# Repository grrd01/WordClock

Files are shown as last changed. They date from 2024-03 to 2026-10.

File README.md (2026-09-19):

# grrd's WordClock

This repository contains the code for the LOLIN (WEMOS) D1 mini Lite (ESP8266) Wordclock offered by FabLab Bern:
[WordClock-Worshop @ FabLab Bern](https://fablab-bern.ch/wordclock-workshop/)

Generate custom clockface:
[SVG-Generator](https://wordclock.collaud.me/)

## Update Arduino Code with Current Frontend

The web interface is automatically generated from the Frontend using Grunt and embedded in `web_interface.h`:

```bash
cd Frontend
yarn install         # (only required on first run)
yarn grunt           # Compiles Frontend and updates web_interface.h
```

After running `yarn grunt`, the file `Backend/Arduino_Berndeutsch_121/web_interface.h` is automatically updated and ready to compile with the Arduino IDE.

The current sketch also supports the optional ESP32-C6 BLE controller. When compiling it for an ESP32, select the custom `partitions.csv` file in the partition scheme menu (or select `Huge APP` on boards that provide that option). The default ESP32 partition leaves only 1.3 MB for the application, which is too small for the web interface and BLE support together. The custom table reserves 3 MB for the application and requires a board with at least 4 MB flash.

Hardware required:

| Anz | Element | Bemerkungen | Preis |
|---:|---|---|---:|
| 1 | [IKEA SANNAHED Bilderrahmen](https://www.ikea.com/ch/en/p/sannahed-frame-black-60459118/) | 25x25cm schwarz | 10.00 |
| 1 | [Glasscheibe 25x25cm](https://www.jumbo.ch/de/bauen-renovieren/glas-kunstglas/kunstglas/floatglas-klar-3-mm/p/5840626) | | 10.00 |
| 1 | [Hartfaserplatte 25x25cm](https://www.jumbo.ch/de/bauen-renovieren/holz/holzzuschnitt/hartfaserplatten/hartfaserplatte-roh-3-mm/p/3890986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) | |  1.00 |
| 1 | [Diffusor](https://de.aliexpress.com/item/1005006113208369.html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) | LGT075J |  1.00 | 
| 1 | [Raster](https://github.com/grrd01/WordClock/blob/main/Hardware/3D_Grid/WordClock_25x25slim/WordClock%2025x25%20slim.stl) | 3D-Druck |  3.00 |
| 1 | [Wemos D1 mini V4.0 USB C](https://de.aliexpress.com/item/1005012133189139.html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) | |  2.00 |
| 0.5 | [LED RGB NeoPixel Stripe](https://de.aliexpress.com/item/2036819167.html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) | 5m, 60LED/m, IP30, not waterproove, white PCB |  9.00 | 
| 1 | [Kondensator 10V 1000µF](https://de.aliexpress.com/item/1005002524973878.html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) | |  0.30 |
| 1 | [Widerstand 470 Ohm](https://de.aliexpress.com/item/1005003342360099.html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) | |  0.05 |
| 1 | [USB-Kabel](https://www.temu.com/ch/60w-schnelllade-usb-typ-c-kabel-3-6-10ft--usb-a-zu-usb-c-ladekabel-kompatibel-mit-samsung-galaxy-iphone--plus-15-pro-15-pro-max-mehr-usb-c-ka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) | 2m |  2.00 |
| 0.5 | [Lötzinn](https://www.berrybase.ch/goobay-loetzinn-bleifrei-oe1-0mm/gewicht-17g-dispenser) | |  2.00 | 
| 2.25m | [Kupferlitze](https://www.berrybase.ch/kupferlitze-isoliert-1x0-14mm-10m/farbe-rot) | 3x75cm rot/blau/schwarz pro Uhr |  1.00 | 
|  10cm | [Schrumpfschlauch](https://de.aliexpress.com/item/4000967042670.html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) | 2mm | |
| 1 | [Controller-Mount](https://github.com/grrd01/WordClock/blob/main/Hardware/3D_Parts/Wemos%20D1%20mini%20Mount.stl) | | |
| 1 | [Cable-Mount](https://github.com/grrd01/WordClock/blob/main/Hardware/3D_Parts/USB-Cable%20Mount.stl) | | |
| 0.5 | [Farbspray](https://www.galaxus.ch/de/s4/product/amsterdam-spruehfarbe-lampenschwarz-040-l-lack-6300169) | | |
| x | [Lötkolben](https://de.aliexpress.com/item/1005005623832147.html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) | | |
| x | [Schmirgelpapier](https://de.aliexpress.com/item/1005005886525600.html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) | |  1.00 |
| x | [Schleifklotz](https://www.galaxus.ch/de/s4/product/walkron-schleifklotz-aus-kork-schleifmittel-37001841) | | |
| x | [Weissleim](https://www.galaxus.ch/de/s4/product/cementit-weiss-100g-mit-drehverschluss-100-g-klebstoff-5633901) | | |
| x | [Heissleim](https://www.galaxus.ch/de/s4/product/i-am-creative-klebesticks-heisskleber-11152396) | | |
| x | [Klebband](https://www.galaxus.ch/de/s4/product/tesa-4344-precision-standard-malerkrepp-fuer-praezises-abdecken-25-mm-klebeband-13502538) | | |

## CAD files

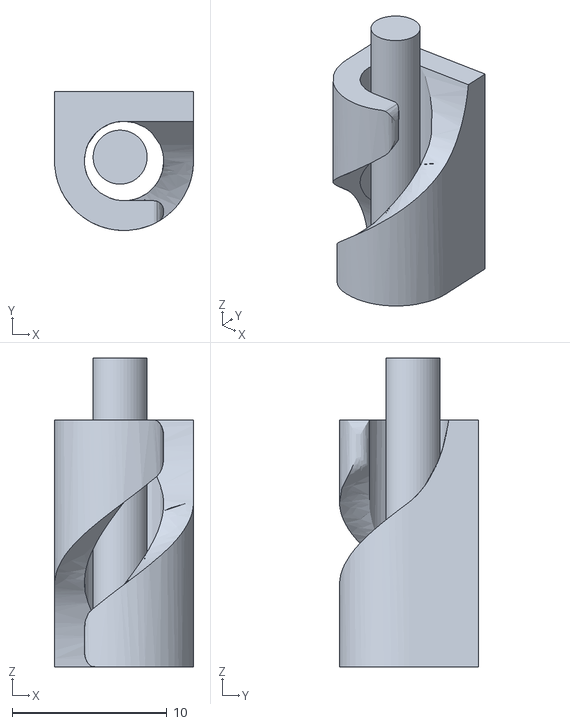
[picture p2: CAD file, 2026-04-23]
Hardware/3D_Parts/USB-Cable Mount.stl
9.00 x 9.00 x 20.0

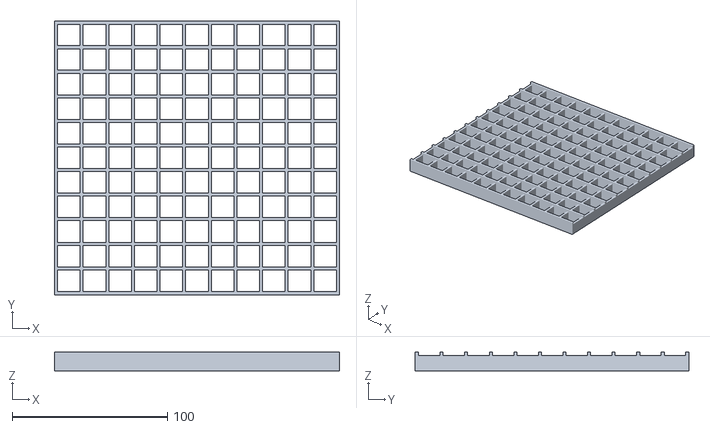
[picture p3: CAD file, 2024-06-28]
Hardware/3D_Parts/WordClock_25x25/WordClock_25x25.stl
183.5 x 176.2 x 12.0

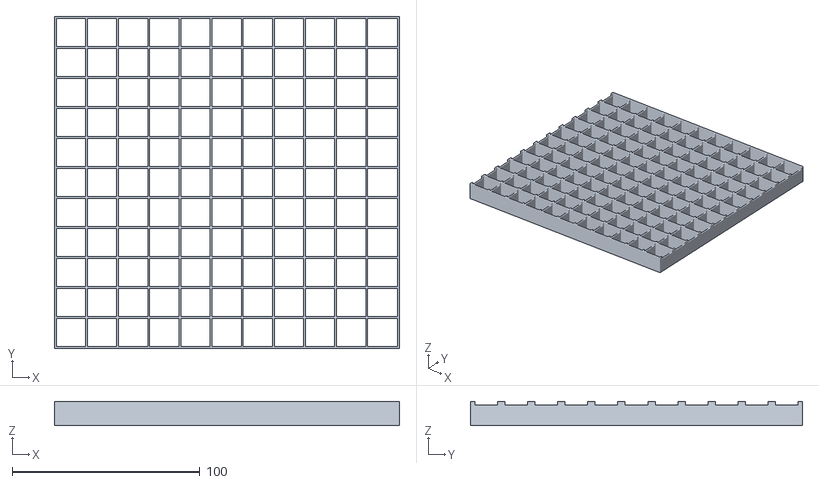
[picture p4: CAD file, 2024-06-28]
Hardware/3D_Parts/WordClock_25x25slim/WordClock 25x25 slim.stl
184.0 x 177.0 x 13.0

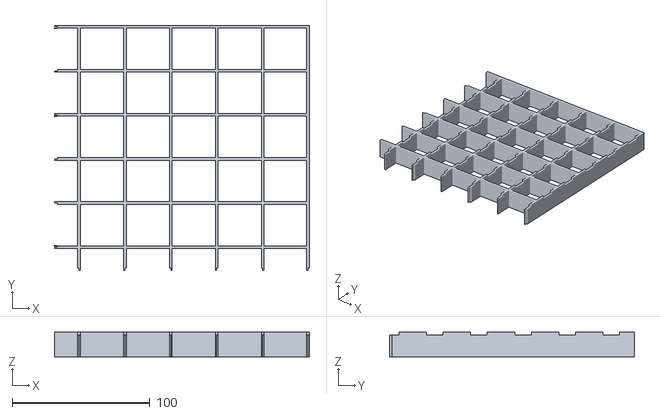
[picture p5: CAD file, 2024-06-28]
Hardware/3D_Parts/WordClock_50x50/WordClock_50x50_B.stl
185.0 x 178.1 x 18.0

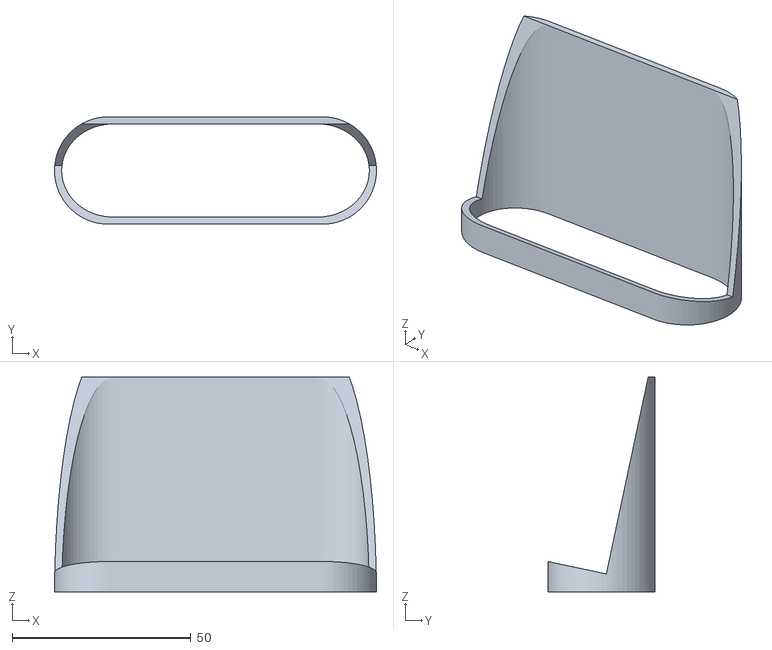
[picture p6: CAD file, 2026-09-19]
Hardware/3D_Parts/WordClock_9x9/WordClockMini_Ständer.stl
90.0 x 30.0 x 60.0

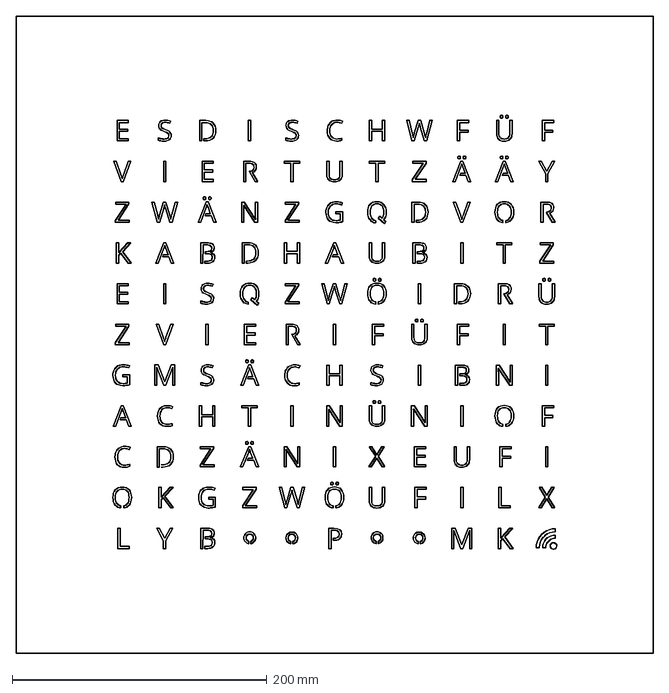
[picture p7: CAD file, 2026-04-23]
Hardware/Clockface/Berndeutsch/Berndeutsch_121_50x50_Stencil.dxf
500.0 x 500.0 mm

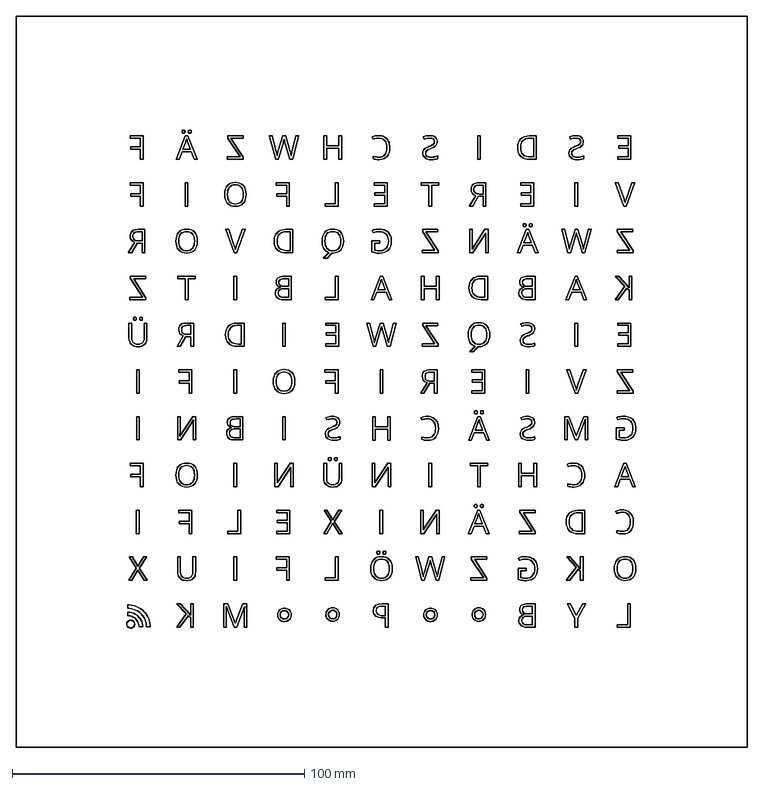
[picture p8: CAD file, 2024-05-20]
Hardware/Clockface/Zürideutsch/Zuerideutsch_121_25x25_Laser.dxf
250.0 x 250.0 mm

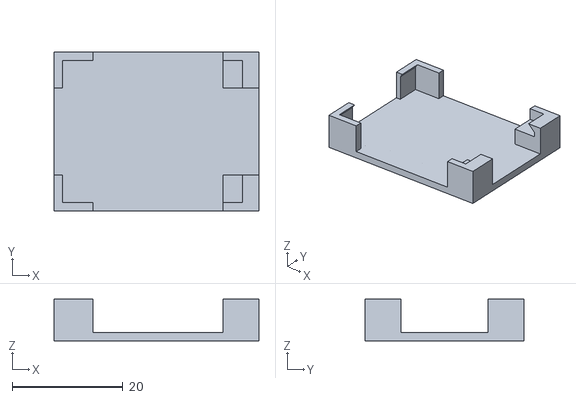
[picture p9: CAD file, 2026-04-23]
Hardware/3D_Parts/Wemos D1 mini Mount.stl
37.0 x 28.7 x 7.50

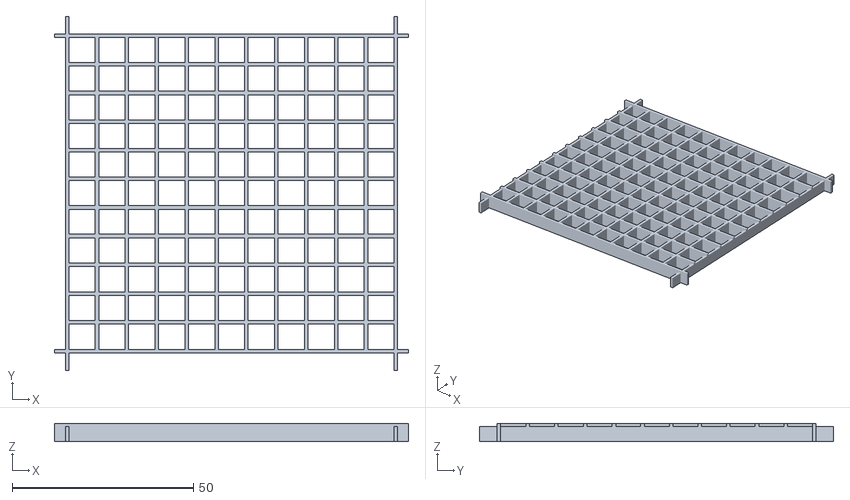
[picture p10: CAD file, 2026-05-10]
Hardware/3D_Parts/WordClock_9x9/WordClock_9x9.stl
97.8 x 97.8 x 5.00

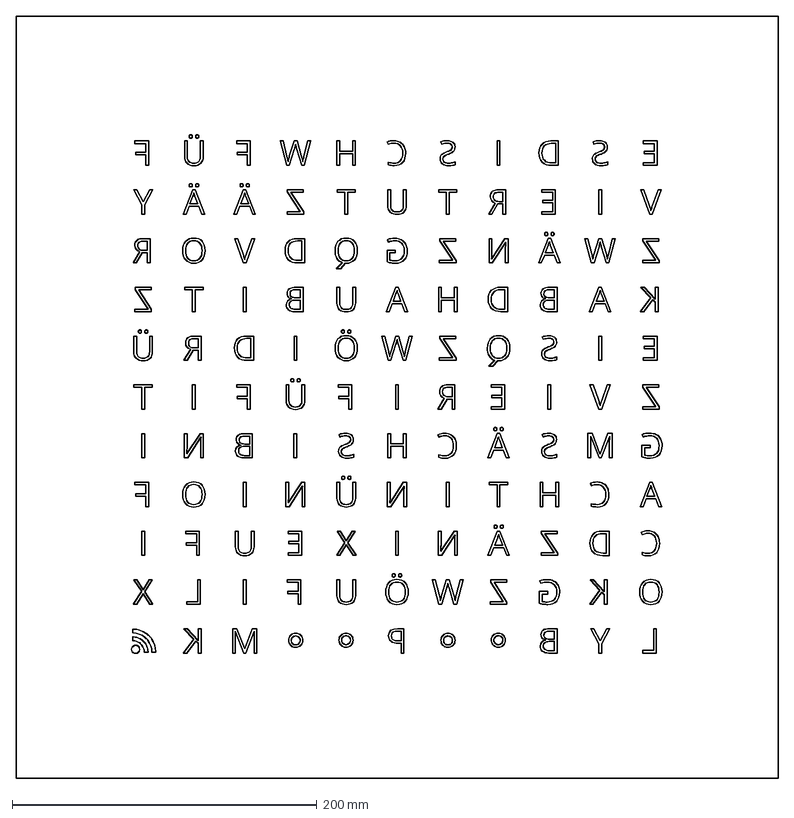
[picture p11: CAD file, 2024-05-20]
Hardware/Clockface/Berndeutsch/Berndeutsch_121_50x50_Laser.dxf
500.0 x 500.0 mm

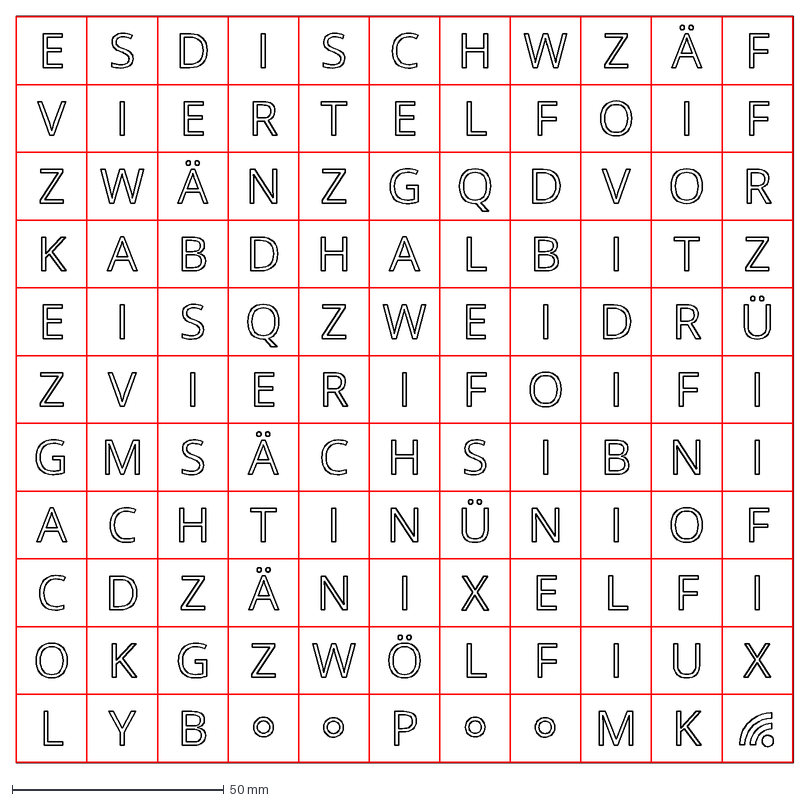
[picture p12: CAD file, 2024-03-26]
Hardware/Clockface/Zürideutsch/Zuerideutsch_121.dxf
183.5 x 176.2 mm

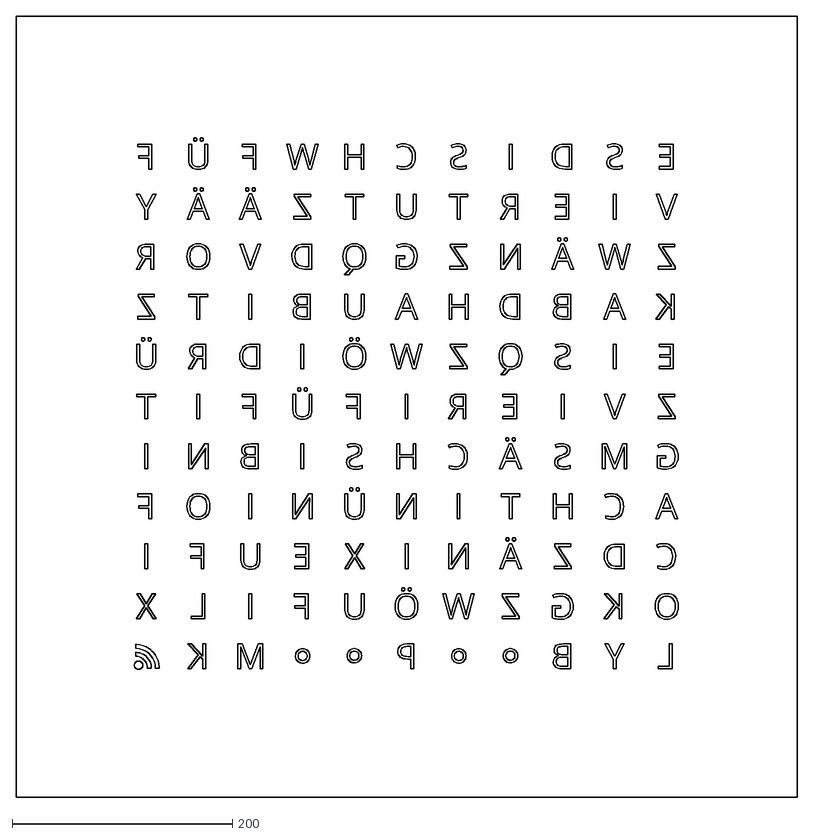
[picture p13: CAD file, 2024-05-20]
Hardware/Clockface/Berndeutsch/Berndeutsch_121_25x25_Laser.dxf
708.7 x 708.7

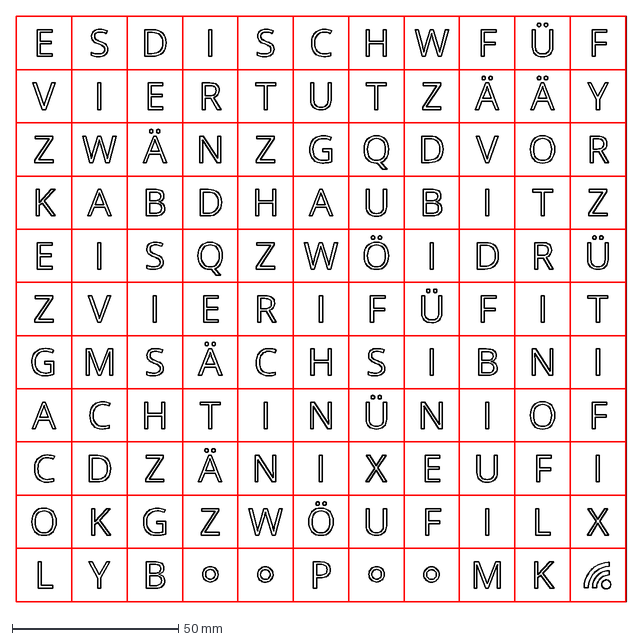
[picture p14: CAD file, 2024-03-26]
Hardware/Clockface/Berndeutsch/Berndeutsch_121.dxf
183.5 x 176.2 mm

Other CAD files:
Hardware/3D_Parts/WordClock_50x50/WordClock_50x50_A.stl

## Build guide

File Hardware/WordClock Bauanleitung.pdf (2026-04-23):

1.

2.
3.

4.

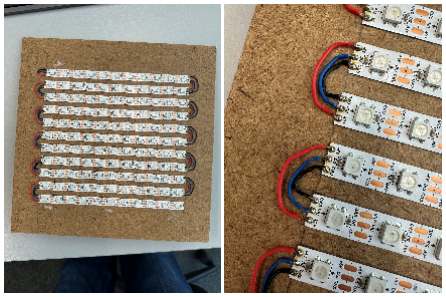
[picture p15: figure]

1.

2.
3.

4.

5.

# 2026 WordClock Bauanleitung

# 1. Clockface / Zifferblatt

Material: 25 x 25 cm Floatglas, Acrylspray

Mit Schleifpapier und Schleifklotz die scharfen Kanten abschleifen ACHTUNG: Die Glasscheibe hat scharfe Kanten und kann zerbrechen! Reinigen /Fingerabdrücke entfernen
Draussen auf Kartonunterlage mit Acrylspray einsprühen
ACHTUNG: Die Farbschicht ist sehr kratzempfindlich!
20 - 30 cm Abstand
mehrere dünne Schichten, Tropfenbildung vermeiden immer auf der selben Seite
horizontal / vertikal abwechseln
neben der Glasscheibe mit dem Sprühen beginnen 5 - 6 x wiederholen, bis kein Licht mehr durchscheint

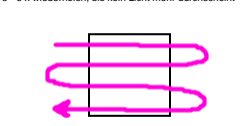
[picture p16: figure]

Wenn die Farbe trocken ist, Beschriftung auf dem Lasercutter einbrennen

# 2. LED-Panel

Material: 25 x 25 cm Hartfaserplatte, LED-Streifen, Kabel

Kabel zuschneiden, an beiden Enden 2 mm abisolieren: Rot (+5V): 1 * 300 mm, 5 * 30 mm, 5 * 49 mm
Blau (Din / Do): 1 * 300 mm, 10 * 38 mm
Schwarz (GND): 1 * 300 mm, 5 * 30 mm, 5 * 49 mm
Vom LED-Streifen 11 Stücke à 11 LEDs mit der Schere entlang der Trennlinie mittig durch die Kupferkontakte abschneiden LED-Streifen gemäss Aufzeichnung auf die Hartfaserplatte kleben
Blauen Schutzstreifen ablösen
ACHTUNG: Pfeilrichtung auf LED-Streifen muss der Aufzeichnung entsprechen!
Die abgeschnittenen Enden der LED-Streifen mit den vorbereiteten Kabelstücken wieder verbinden:
Mit Lötkolben die Kontaktstellen auf den LED-Streifen 2 Sekunden aufheizen, danach einen Tropfen Lötzinn über die Verbindungsstelle Die abisolierten Kabelstückchen so verdrehen, dass keine Kupferdrähtchen abstehen
Die Kabelstückchen mit Klebband auf einer Unterlage fixieren und sehr kurz mit dem Lötkolben aufheizen und mit ein wenig Lötzinn "verzinnen"
Mit Klebeband das passende Stück Kabel über dem Zinntropfen fixieren, den Tropfen mit dem Lötkolben aufheizen, bis das Kabel darin versinkt
Die langen Kabel (300mm) an die drei Kontakte (DIN = Data in, VBUS = +5V, GND = Ground) oben links anlöten und durchs Loch auf die Rückseite ziehen

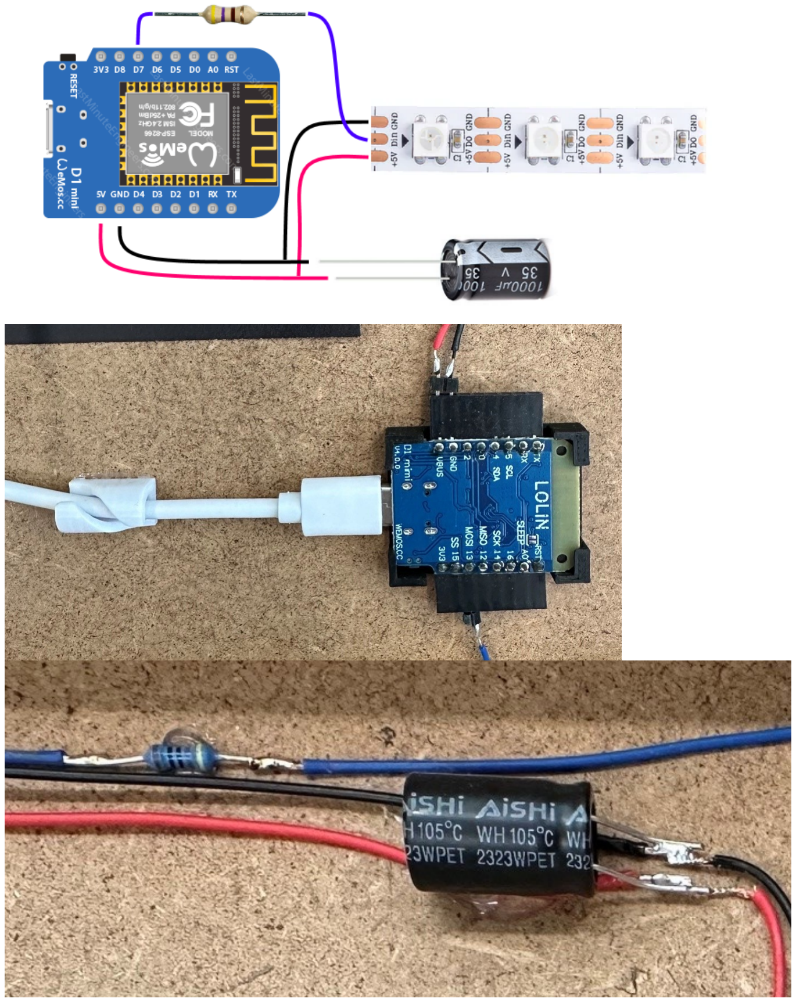
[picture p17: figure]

1.
2.

3.
4.
5.

# 3. Controller

Material: Wemos D1 mini, 1000mF Kondensator, 470 Ohm Widerstand, Steckverbindungen

Blaues Datenkabel trennen, 470 Ohm Widerstand dazwischen löten, mit Schrumpfschlauch isolieren Rotes und schwarzes Kabel parallel trennen, Kondensator anlöten
ACHTUNG: +/- Polung beachten!
mit Schrumpfschlauch isolieren
Weibliche Steckverbindung auf Controller löten
männliche Steckverbindung auf weibliche stecken Kabel am männlichen Header anlöten:
rot = +5V zu VBUS / 5V

6.

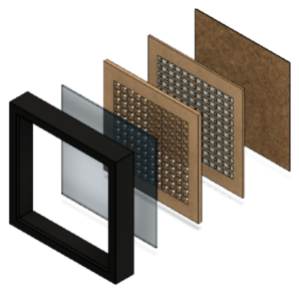
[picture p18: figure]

1.
2.
3.
4.
5.
6.
7.

schwarz = GND zu GND / G
blau = Din zu D7 / GPIO13 / MOSI LED-Test-Script aufspielen, LEDs testen

# 4. Rahmen

Material: IKEA-Bilderrahmen, 3D-gedruckter Raster, 25 x 25 cm Diffusor-Folie, Distanzhalter-Rahmen

Glasscheibe (Farbschicht innen) in den Rahmen legen
Diffusor-Folie auf Mass schneiden und einlegen
Raster mit Heissleim auf LED-Platte fixieren (Aussparung für LED-Streifen beachten) LED-Platte einlegen
Distanzhalter-Rahmen einlegen
Aussparung für Kabel in die schwarze Abdeckungsplatte des Bilderrahmens feilen USB-Kabel und Abdeckplatte einlegen - Fertig!

Viel Spass mit deiner neuen WordClock!

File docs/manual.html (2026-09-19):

Gib dire WordClock chli Strom. Wenn si parat isch, lüchtet "FIX WLAN". Dini Uhr möcht sech mit dim Wlan verbinde.

Jetzt muesch uf dim Handy oder Laptop zu de Wlan-Iistellige, u dört söttsch es nöis Wlan gseh, wo WordClock heisst. Das muesch usläse. När sött im Browser e Site ufgah, wo du dr Uhr dr Name u ds Passwort vo dim Wlan chasch säge. Das muesch nume z erste Mau mache, d Uhr spicheret sech ds Passwort.

Falls die Site nid outomatisch ufgeit, chasch im Browser ids Adräss-Fäud "192.168.4.1" iigäh.

Wenn sech d WordClock mit dim Wlan het chönne verbinde, seit si dr ihri IP-Adrässe. Uf dr Uhr lüchtet nachenand öppe so öppis uf:

EIS NÜNI ZWÖI ° EIS SÄCHSI ACHTI ° EIS ° EIS EIS O

Bi dir chöi die Zahle chli anders sii. "°" bedütet Punkt (.) u "O" bedütet Null (0), auso i üsem Bispil "192.168.1.110".

Sobald d Uhr d Zyt aazeigt, chasch im Browser uf dim Handy i ds Adräss-Fäud "wordclock.local" iigäh. Das sött d WordClock-App uftue. Wenn das nid funktioniert, chasch d IP-Adrässe näh.

Ir WordClock-App chasch zum Bispiu d Farb vor Aazeig ändere. Oder Snake spile. Klick eifach unde rächts uf ds Zahnrad.

Ig wünsche dir viu Vergnüege mit dire nöie WordClock!

Gérard Tyedmers grrd.ch grrd@gmx.net

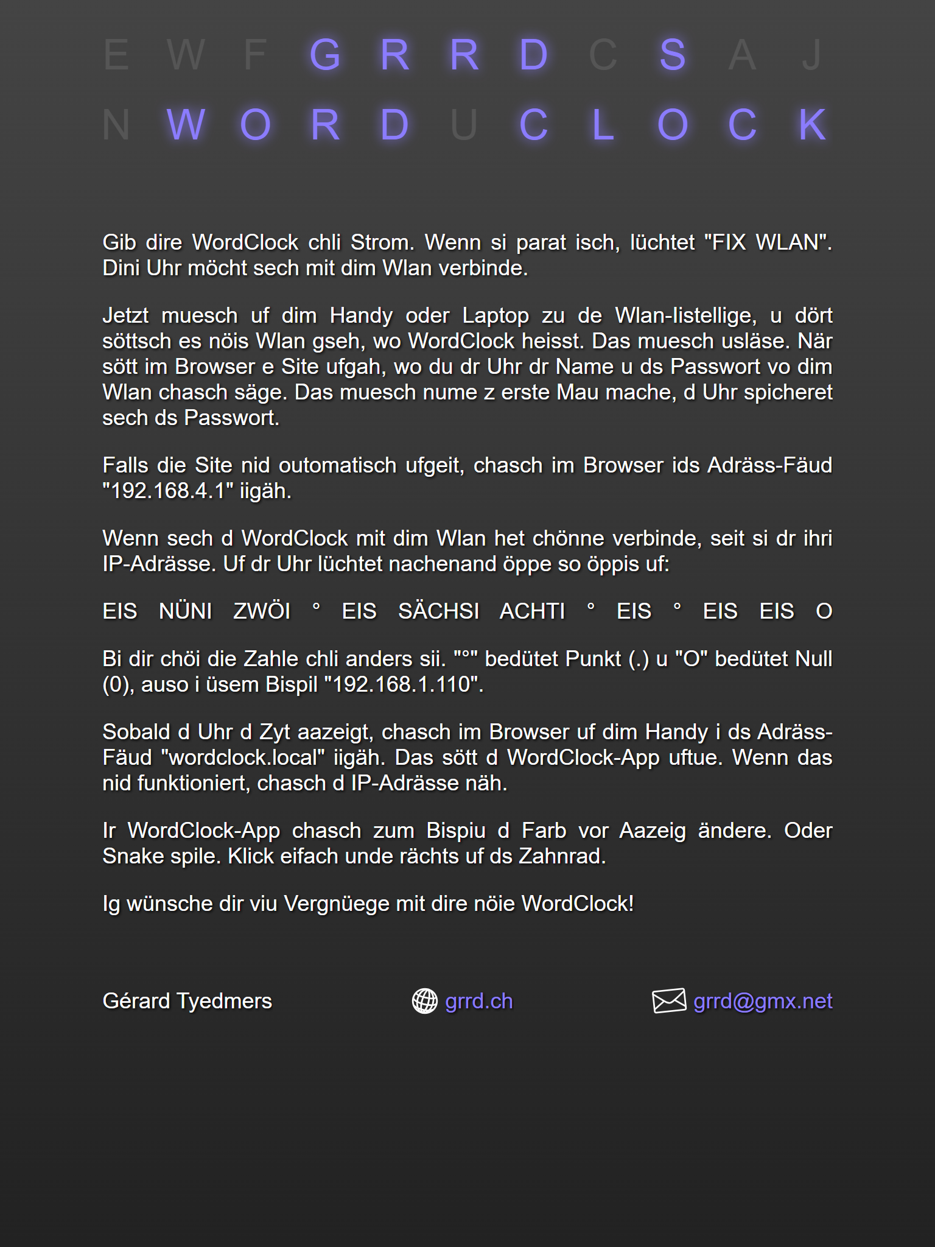
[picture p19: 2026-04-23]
Hardware/usermanual.png

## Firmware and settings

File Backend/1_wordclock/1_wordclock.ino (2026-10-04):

/////////////////////////////////////////////
//
// Wordclock Program for Wemos D1 Mini (ESP8266) or XIAO ESP32C6
// Based on sripts and snippets from:
// Rui Santos http://randomnerdtutorials.com
// neotrace https://www.instructables.com/id/WORK-IN-PROGRESS-Ribba-Word-Clock-With-Wemos-D1-Mi/
// and others
//
// Kurt Meister, 2018-12-24 | Edit: 2023-04-29
// Thanks to Manuel Meister for refactoring and adding automated summertime conversion.
//
// Gérard Tyedmers, 2024-01-15
// - Web-Interface added (http://wordclock.local/)
// - ESP32-Support added
//
// Daniel Illi, 2026-01-13
// - Extract Webapp-String to separate file
/////////////////////////////////////////////

/////////////////////////////////////////////
//
// Connection scheme for supported hardware:
//
// - Adafruit_NeoPixel WS2812B
//     VBUS/5V        -> +5V
//     D7/GPIO13/MOSI -> DIN
//     GND/G          -> GND
// - Touch-Sensor TTP223
//     3.3v           -> VCC
//     D5/GPIO14/SCLK -> I/O
//     GND/G          -> GND
// - PushButton
//     D5/GPIO14/SCLK -> one side of button
//     GND/G          -> other side of button
// - Brightness-Sensor GY-302 BH1750
//     3.3v           -> VCC
//     D1/GPIO5/SCL   -> SCL
//     D2/GPIO4/SDA   -> SDA
//     GND/G          -> GND
//                       ADDR not used
// - Passive Buzzer
//     VBUS/5V        -> VCC
//     D6/GPIO12/MISO -> I/O
//     GND/G          -> GND
// - Temperature/Humidity-Sensor SHT40
//     3.3v           -> VCC
//     D1/GPIO5/SCL   -> SCL
//     D2/GPIO4/SDA   -> SDA
//     GND/G          -> GND
// - ShanWan Q36 Bluetooth Controller
//
/////////////////////////////////////////////

/////////////////////////////////////////////
//
// IMPORTANT: To compile, choose Tools - Partition Scheme - Huge APP (3MB No OTA/1MB SPIFFS)
//
/////////////////////////////////////////////

// set name for access-point and mdns-server
const char* version = "wordclock";

// define if a touch sensor is used for power on/off: 1 = yes, 0 = no
#define USE_TOUCH_SENSOR 0

// define if a push-button is used for power on/off: 1 = yes, 0 = no
#define USE_PUSH_BUTTON 0

// define if a brightness sensor is used to control led brightness:  1 = yes, 0 = no
#define USE_BRIGHTNESS_SENSOR 0

// define if a passive buzzer is used for alarm signals:  1 = yes, 0 = no
#define USE_PASSIVE_BUZZER 0

// define if a temperature/humidity sensor is used:  1 = yes, 0 = no
#define USE_TEMP_HUMID_SENSOR 0

// define if a ShanWan Q36 Bluetooth Controller can be paired: 1 = yes, 0 = no
#define USE_CONTROLLER 1

// ToDo: Bug - Tetris: während Animation von gelöschten Zeilen löscht Down auf Controller zusätzliche Zeilen
// ToDo: Bug - Controller-Pairing funktioniert manchmal nicht oder lässt Uhr abstürzen
// ToDo: Feature - Brightness-Sensor
// ToDo: Feature - Passive-Buzzer / Wecker / Timer
// ToDo: Feature - Temperature/Humidity-Sensor SHT40

#include <Arduino.h>

#if defined(ARDUINO_ARCH_ESP8266)
  #include <ESP8266WiFi.h>
  #include <ESP8266mDNS.h>
#elif defined(ARDUINO_ARCH_ESP32)
  #include <WiFi.h>
  #include <ESPmDNS.h>
  #if USE_CONTROLLER
    #include <NimBLEDevice.h>
  #endif
#else
  #error Unsupported platform
#endif

#include <WiFiManager.h>        // v2.0.17
#include <WiFiUdp.h>
#include <WebSocketsServer.h>   // v2.7.1
#include <TimeLib.h>            // v1.6.1
#include <Timezone.h>           // v1.2.6
#include <Adafruit_NeoPixel.h>  // v1.15.2
#include <pgmspace.h>
#include <EEPROM.h>
#include "web_interface.h"

#define MATRIX_WIDTH 11
#define MATRIX_HEIGHT 11

// Set web server port number to 80, WebSocketsServer to 81
WiFiServer server(80);
WebSocketsServer webSocket = WebSocketsServer(81);

// Variable to store the HTTP request
String header;

// Auxiliar variables to store the web parameters
const uint8_t numPixels = 121;
uint8_t rgbRed = 255;
uint8_t rgbGreen = 255;
uint8_t rgbBlue = 255;
uint8_t power = 1;
uint8_t darkMode = 1;
uint8_t ghost = 1;
uint8_t effect = 0; // 0 = none, 1 = colorWheel, 2 = rainbow, 3 = matrix, 4 = pulse, 5 = typewriter
int effectSpeed = 200;
int effectWait = 200;
bool effectChange = false;
bool lastTouchStage = false;
uint16_t frame = 0;
// Matrix-Drops
struct Drop {
  float y; // aktuelle Position (kann zwischen den Zeilen liegen)
  float speed; // Geschwindigkeit (Zeilen pro Frame)
  uint8_t length; // Abdunklungslänge
  uint8_t maxBrightness; // Maximale Helligkeit (0..255)
  bool active; // Ob dieser Drop aktiv ist
};
Drop drops[11][2]; // 11 Spalten, bis zu 2 Drops pro Spalte
uint16_t dropCooldown[11]; // Cooldown pro Spalte bis zum nächsten neuen Drop

// EEPROM addresses for persistent variables
const uint8_t eepromAddrRed = 0;
const uint8_t eepromAddrGreen = 1;
const uint8_t eepromAddrBlue = 2;
const uint8_t eepromAddrDarkMode = 3;
const uint8_t eepromAddrGhost = 4;
const uint8_t eepromAddrEffect = 5;
const uint8_t eepromAddrEffectSpeedLow = 6;   // effectSpeed is int (2 bytes)
const uint8_t eepromAddrEffectSpeedHigh = 7;
const uint8_t eepromAddrTetrisHigh = 8;
const uint8_t eepromAddrSnakeHigh = 9;
const uint8_t eepromAddrSameGameHighLow = 10;  // sameGameHighScore is int (2 bytes)
const uint8_t eepromAddrSameGameHighHigh = 11;

#if USE_CONTROLLER
static NimBLEClient* pClient = nullptr;
static bool doConnect = false;
static bool startDiscovery = false;
static NimBLEAdvertisedDevice* targetDevice = nullptr;
#endif
uint8_t connectedControllers = 0;

// Current time
unsigned long currentTime = millis();
// Previous time
unsigned long previousTime = 0; 
// Define timeout time in milliseconds (example: 2000ms = 2s)
const long timeoutTime = 2000;

uint8_t wordClockMinute = 62;
uint8_t wordClockHour = 0;
uint8_t lastMinuteWordClock = 61;

const uint8_t NTP_PACKET_SIZE = 48; // NTP time is in the first 48 bytes of message
byte packetBuffer[NTP_PACKET_SIZE]; //buffer to hold incoming & outgoing packets
static const char ntpServerName[] = "0.ch.pool.ntp.org";

const uint8_t timeZone = 0;     // Central European Time

//Central European Time (Frankfurt, Paris)
TimeChangeRule CEST = {"CEST", Last, Sun, Mar, 2, 120};     //Central European Summer Time
TimeChangeRule CET = {"CET", Last, Sun, Oct, 3, 60};       //Central European Standard Time
Timezone CE(CEST, CET);
time_t timeWithDST;

WiFiUDP ntpUDP;
unsigned int localPort = 8888;  // local port to listen for UDP packets

static uint32_t Black = Adafruit_NeoPixel::Color(0, 0, 0);
static uint32_t White = Adafruit_NeoPixel::Color(49, 52, 34);
static uint32_t Grey = Adafruit_NeoPixel::Color(3, 3, 3);
static uint32_t Cornflower = Adafruit_NeoPixel::Color(8, 7, 16);
static uint32_t Red = Adafruit_NeoPixel::Color(100, 0, 5);
static uint32_t Orange = Adafruit_NeoPixel::Color(100, 25, 0);
static uint32_t Yellow = Adafruit_NeoPixel::Color(100, 90, 0);
static uint32_t Green = Adafruit_NeoPixel::Color(10, 95, 0);
static uint32_t Blue = Adafruit_NeoPixel::Color(0, 20, 85);
static uint32_t Purple = Adafruit_NeoPixel::Color(85, 0, 100);
static uint32_t Cyan = Adafruit_NeoPixel::Color(00, 100, 100);

static uint32_t GameColors[] = {Red, Orange, Yellow, Green, Blue, Purple, Cyan};

uint32_t colorDay  = Adafruit_NeoPixel::Color(rgbRed / 5, rgbGreen / 5, rgbBlue / 5);
uint32_t colorNight  = Adafruit_NeoPixel::Color(rgbRed / 25, rgbGreen / 25, rgbBlue / 25);

uint32_t foregroundColor = colorDay;
uint32_t backgroundColor = Black;

// Don't light up WiFi, only on requests
uint32_t wifiColor = Black;

/*
| E | S | D | I | S | C | H | W | F | Ü | F |
| V | I | E | R | T | U | T | Z | Ä | Ä | Y |
| Z | W | Ä | N | Z | G | Q | D | V | O | R |
| K | A | B | D | H | A | U | B | I | T | Z |
| E | I | S | Q | Z | W | Ö | I | D | R | Ü |
| Z | V | I | E | R | I | F | Ü | F | I | T |
| G | M | S | Ä | C | H | S | I | B | N | I |
| A | C | H | T | I | N | Ü | N | I | O | F |
| C | D | Z | Ä | N | I | X | E | U | F | I |
| O | K | G | Z | W | Ö | U | F | I | L | X |
| L | Y | B | ° | ° | P | ° | ° | M | K | @ |
 */

static int8_t WordEs[] = {0, 1, -1};
static int8_t WordIst[] = {3, 4, 5, 6, -1};
static int8_t WordHalb[] = {39, 38, 37, 36, 35, -1};

static int8_t WordFix[] = {77, 98, 99, -1};
static int8_t SymbolWifi[] = {120, -1};
static int8_t WordNach[] = {42, 41, -1};
static int8_t WordVor[] = {30, 31, 32, -1};

// Stunde
static int8_t WordStundeEins[] = {44, 45, 46, -1};                     // EIS
static int8_t WordStundeZwei[] = {48, 49, 50, 51, -1};                 // ZWÖI
static int8_t WordStundeDrei[] = {52, 53, 54, -1};                     // DRÜ
static int8_t WordStundeVier[] = {64, 63, 62, 61, 60, -1};             // VIERI
static int8_t WordStundeFuenf[] = {59, 58, 57, 56, -1};                // FÜFI
static int8_t WordStundeSechs[] = {68, 69, 70, 71, 72, 73, -1};        // SÄCHSI
static int8_t WordStundeSieben[] = {72, 73, 74, 75, 76, -1};           // SIBNI
static int8_t WordStundeAcht[] = {87, 86, 85, 84, 83, -1};             // ACHTI
static int8_t WordStundeNeun[] = {82, 81, 80, 79, -1};                 // NÜNI
static int8_t WordStundeZehn[] = {90, 91, 92, 93, -1};                 // ZÄNI
static int8_t WordStundeElf[] = {95, 96, 97, 98, -1};                  // EUFI
static int8_t WordStundeZwoelf[] = {106, 105, 104, 103, 102, 101, -1}; // ZWÖUFI

static int8_t *WordStunden[] = {WordStundeZwoelf, WordStundeEins, WordStundeZwei, WordStundeDrei, WordStundeVier,
                             WordStundeFuenf, WordStundeSechs, WordStundeSieben, WordStundeAcht, WordStundeNeun,
                             WordStundeZehn, WordStundeElf, WordStundeZwoelf
};

// Minute
static int8_t WordMinFuenf[] = {8, 9, 10, -1};                   // FÜF
static int8_t WordMinZehn[] = {14, 13, 12, -1};                  // ZÄÄ
static int8_t WordMinViertel[] = {21, 20, 19, 18, 17, 16, -1};   // VIERTU
static int8_t WordMinZwanzig[] = {22, 23, 24, 25, 26, 27, -1};   // ZWÄNZG
static int8_t WordMinTicks[] = {113, 114, 116, 117, -1};         // ** **

static int8_t *WordMinuten[] = {WordMinFuenf, WordMinZehn, WordMinViertel, WordMinZwanzig, WordMinFuenf};

// aktueller und letzter Zeit-Satz
int8_t satzalt[30] = {-1};
int8_t satzneu[30] = {-1};
uint8_t satzindex = 0;

Adafruit_NeoPixel pixels = Adafruit_NeoPixel(numPixels, D7, NEO_GRB + NEO_KHZ800);

// How long this state should be displayed
int wifiWait = 0;

// Snake variables
int8_t snake[120];
uint8_t snakeLen = 3;
uint8_t snakeHighScore = 0;
int snakeNext = -1;
int snakeSnack = -2;  // pixel 0-120
String snakeDir = ""; // snake, up, right, down, left, stop
String snakePrevDir = "";
unsigned long  snakeSpeed;
unsigned long snakeLastMove = 0;
bool inSnake = false;

// SameGame variables
#define COLOR_COUNT 4
bool inSameGame = false;
enum GameStatus {
  STATUS_PLAYING,
  STATUS_WON,
  STATUS_STUCK
};

GameStatus gameStatus = STATUS_PLAYING;
int sameGameScore = 0;
int sameGameHighScore = 0;
uint8_t movesMade = 0;
uint8_t cursorX = MATRIX_WIDTH / 2;
uint8_t cursorY = MATRIX_HEIGHT / 2;
bool cursorBlinkVisible = true;
unsigned long lastBlinkToggle = 0;
const unsigned long blinkInterval = 350;
int collectGroup(int startX, int startY, int groupX[], int groupY[]);
bool inBounds(int x, int y);

// Tetris variables
uint8_t board[11][11] = {0}; // 0 = empty, >0 = color index, shared with SameGame
uint8_t tetrisScore = 0;
uint8_t tetrisHighScore = 0;
bool inTetris = false;
unsigned long lastDrop = 0;
const unsigned long dropInterval = 600; // ms

// Tetromino definitions (4x4 matrix for each shape)
const uint8_t tetrominos[7][4][4] = {
  // I
  {
    {0,0,0,0},
    {1,1,1,1},
    {0,0,0,0},
    {0,0,0,0}
  },
  // J
  {
    {0,0,0,0},
    {0,1,0,0},
    {0,1,1,1},
    {0,0,0,0}
  },
  // L
  {
    {0,0,0,0},
    {0,0,1,0},
    {1,1,1,0},
    {0,0,0,0}
  },
  // O
  {
    {0,0,0,0},
    {0,1,1,0},
    {0,1,1,0},
    {0,0,0,0}
  },
  // S
  {
    {0,0,0,0},
    {0,1,1,0},
    {1,1,0,0},
    {0,0,0,0}
  },
  // T
  {
    {0,0,0,0},
    {0,1,0,0},
    {1,1,1,0},
    {0,0,0,0}
  },
  // Z
  {
    {0,0,0,0},
    {1,1,0,0},
    {0,1,1,0},
    {0,0,0,0}
  }
};

// Current piece state
int currentTetromino, rotation, posX, posY;
uint8_t currentPiece[4][4]; // Store current piece with rotation applied
bool gameOver = false;

// Map (x, y) to LED index for serpentine wiring
uint8_t xyToIndex(uint8_t x, uint8_t y) {
  if (y % 2 == 0) {
    return y * 11 + x;
  } else {
    return y * 11 + (10 - x);
  }
}

// Hilfsfunktion: Prüft, ob LED in Array enthalten ist
bool inArray(uint8_t led, int8_t *arr) {
  for (uint8_t i = 0; arr[i] != -1; i++) {
    if (arr[i] == led) return true;
  }
  return false;
}

// Hilfsfunktion: HSV zu RGB 
uint32_t colorWheel(byte pos) {
  pos = 255 - pos;
  if (pos < 85) {
    return pixels.Color(255 - pos * 3, 0, pos * 3);
  }
  if (pos < 170) {
    pos -= 85;
    return pixels.Color(0, pos * 3, 255 - pos * 3);
  }
  pos -= 170;
  return pixels.Color(pos * 3, 255 - pos * 3, 0);
}
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
void loop() {
  WiFiClient client = server.available();   // Listen for incoming clients
  webSocket.loop();
  if (client) {                             // If a new client connects,
    String currentLine = "";                // make a String to hold incoming data from the client
    currentTime = millis();
    previousTime = currentTime;
    while (client.connected() && currentTime - previousTime <= timeoutTime) { // loop while the client's connected
      currentTime = millis();
      if (client.available()) {             // if there's bytes to read from the client,
        char c = client.read();             // read a byte, then
        //Serial.write(c);                    // print it out the serial monitor
        header += c;
        if (c == '\n') {                    // if the byte is a newline character
          // if the current line is blank, you got two newline characters in a row.
          // that's the end of the client HTTP request, so send a response:
          if (currentLine.length() == 0) {
            if (header.indexOf("mastermind") >= 0) {
              // Client is playing mastermind game:
              const char *url = header.c_str();

              mastermindCodeTry[3] = extractParameterValue(url, "c4=");
              if (!inMastermind && mastermindCodeTry[3] == 0 && power == 1) {
                // start new mastermind game
                startMastermind();
              } else if (inMastermind && mastermindCodeTry[3] == 7) {
                // exit current mastermind game
                inMastermind = false;
                satzneu[0] = -1;
                lastMinuteWordClock = 61;
              } else if (inMastermind && mastermindCodeTry[3] != 0 && mastermindCodeTry[3] != 7) {
                // restart a new game if needed
                mastermindCodeTryBackup[3] = mastermindCodeTry[3];
                if (mastermindTry == 11 || mastermindPlace == 4) {
                  startMastermind();
                }
                // evaluate players try
                mastermindCodeTry[3] = mastermindCodeTryBackup[3];
                mastermindCodeTry[2] = extractParameterValue(url, "c3=");
                mastermindCodeTry[1] = extractParameterValue(url, "c2=");
                mastermindCodeTry[0] = extractParameterValue(url, "c1=");

                evaluateMastermind();
              }
              client.println(F("HTTP/1.1 200 OK"));
              client.println(F("Content-type:application/json"));
              client.println(F("Connection: close"));
              client.println();
              client.println(F("{\"place\":"));
              client.println(mastermindPlace);
              client.println(F(", \"color\":"));
              client.println(mastermindColor);
              client.println(F(", \"try\":"));
              client.println(mastermindTry);
              client.println(F("}"));
            } else if (header.indexOf("wordguessr") >= 0 && power == 1) {
              // Client is playing wordguessr game:
              if (header.indexOf("new") >= 0) {
                if (!inWordGuessr) {
                  // start new wordguessr game
                  inWordGuessr = true;
                  inSnake = false;
                  inTetris = false;
                  inSameGame = false;
                  inMastermind = false;
                  wordGuessrNewGuess();
                  wordGuessrAlert = millis();
                }
                wordGuessrScore = -1;
              } else if (header.indexOf("exit") >= 0 && inWordGuessr) {
                // exit current wordguessr game
                inWordGuessr = false;
                satzneu[0] = -1;
                lastMinuteWordClock = 61;
                wordGuessrScore = -2;
              } else if (inWordGuessr) {
                int startIndex = header.indexOf("=") + 1; // Sucht die Position des ersten "="-Zeichens
                int endIndex = header.indexOf(' ', startIndex);
                String word = header.substring(startIndex,endIndex); // Extrahiert den Teil des Strings nach dem "="-Zeichen
                word.replace("%C3%84", "Ä");
                word.replace("%C3%96", "Ö");
                word.replace("%C3%9C", "Ü");
                if (word == wordGuessrActiveWord) {
                  // right guess
                  wordGuessrScore = 1;
                  lightup(wordGuessrActiveWordIndex, Green);
                  pixels.show();
                  wordGuessrNewGuess();
                  wordGuessrAlert = millis() + 100;
                } else {
                  // wrong guess
                  wordGuessrScore = 0;
                  lightup(wordGuessrActiveWordIndex, Red);
                  pixels.show();
                  wordGuessrAlert = millis() + 100;
                }
              }
              client.println(F("HTTP/1.1 200 OK"));
              client.println(F("Content-type:application/json"));
              client.println(F("Connection: close"));
              client.println();
              client.println(F("{\"score\":"));
              client.println(wordGuessrScore);
              client.println(F("}"));
            } else if (header.indexOf("update_params") >= 0) {
              // Get new params from client:
              const char *url = header.c_str();
              if (extractParameterValue(url, "ghost=") == 1) {
                ghost = 1;
              } else {
                ghost = 0;
              }
              // Save ghost to EEPROM if it changed
              uint8_t storedGhost = EEPROM.read(eepromAddrGhost);
              if (storedGhost != ghost) {
                effectChange = true;
                EEPROM.write(eepromAddrGhost, ghost);
                EEPROM.commit();
              }
              if (extractParameterValue(url, "power=") == 1) {
                if (power == 0) {
                  satzneu[0] = -1;
                }
                power = 1;
              } else {
                power = 0;
                blank();
                pixels.show();
              }
              if (extractParameterValue(url, "speed=") >= 50 && extractParameterValue(url, "speed=") <= 2000) {
                effectSpeed = (extractParameterValue(url, "speed=") - 48) * 4; // map 50-2000 from WebParameter to 8-7808 in Arduino
              }
              // Save effectSpeed to EEPROM if it changed
              int storedValueInt = (EEPROM.read(eepromAddrEffectSpeedHigh) << 8) | EEPROM.read(eepromAddrEffectSpeedLow);
              if (storedValueInt != effectSpeed) {
                effectChange = true;
                EEPROM.write(eepromAddrEffectSpeedLow, effectSpeed & 0xFF);
                EEPROM.write(eepromAddrEffectSpeedHigh, (effectSpeed >> 8) & 0xFF);
                EEPROM.commit();
              }
              if (extractParameterValue(url, "darkmode=") == 1) {
                darkMode = 1;
              } else {
                darkMode = 0;
              }
              // Save darkMode to EEPROM if it changed
              uint8_t storedDarkMode = EEPROM.read(eepromAddrDarkMode);
              if (storedDarkMode != darkMode) {
                EEPROM.write(eepromAddrDarkMode, darkMode);
                EEPROM.commit();
              }
              if (extractParameterValue(url, "effect=") >= 0 && extractParameterValue(url, "effect=") <= 5) {
                effect = extractParameterValue(url, "effect=");
              }
              // Save effect to EEPROM if it changed
              uint8_t storedEffect = EEPROM.read(eepromAddrEffect);
              if (storedEffect != effect) {
                effectChange = true;
                EEPROM.write(eepromAddrEffect, effect);
                EEPROM.commit();
              }
              if (extractParameterValue(url, "blue=") >= 0 && extractParameterValue(url, "blue=") <= 255) {
                rgbBlue = extractParameterValue(url, "blue=");
              }
              // Save rgbBlue to EEPROM if it changed
              uint8_t storedBlue = EEPROM.read(eepromAddrBlue);
              if (storedBlue != rgbBlue) {
                effectChange = true;
                EEPROM.write(eepromAddrBlue, rgbBlue);
                EEPROM.commit();
              }
              if (extractParameterValue(url, "green=") >= 0 && extractParameterValue(url, "green=") <= 255) {
                rgbGreen = extractParameterValue(url, "green=");
              }
              // Save rgbGreen to EEPROM if it changed
              uint8_t storedGreen = EEPROM.read(eepromAddrGreen);
              if (storedGreen != rgbGreen) {
                effectChange = true;
                EEPROM.write(eepromAddrGreen, rgbGreen);
                EEPROM.commit();
              }
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

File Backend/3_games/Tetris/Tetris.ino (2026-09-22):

// Tetris for ESP8266 with Adafruit NeoPixel 11x11 serpentine matrix
#include <ESP8266WiFi.h>
#include <ESP8266WebServer.h>
#include <Adafruit_NeoPixel.h>
#include <WiFiManager.h>
#include <WebSocketsServer.h>

#define LED_PIN    D7
#define LED_COUNT  121
#define MATRIX_WIDTH  11
#define MATRIX_HEIGHT 11

Adafruit_NeoPixel strip(LED_COUNT, LED_PIN, NEO_GRB + NEO_KHZ800);
ESP8266WebServer server(80);
WiFiManager wifiManager;
WebSocketsServer webSocket = WebSocketsServer(81);

// forward declarations
void webSocketEvent(uint8_t num, WStype_t type, uint8_t * payload, size_t length);

// Game variables
uint8_t board[MATRIX_HEIGHT][MATRIX_WIDTH] = {0}; // 0 = empty, >0 = color index
int score = 0;

// Tetromino definitions (4x4 matrix for each shape)
const uint8_t tetrominos[7][4][4] = {
  // I
  {
    {0,0,0,0},
    {1,1,1,1},
    {0,0,0,0},
    {0,0,0,0}
  },
  // J
  {
    {0,0,0,0},
    {0,1,0,0},
    {0,1,1,1},
    {0,0,0,0}
  },
  // L
  {
    {0,0,0,0},
    {0,0,1,0},
    {1,1,1,0},
    {0,0,0,0}
  },
  // O
  {
    {0,0,0,0},
    {0,1,1,0},
    {0,1,1,0},
    {0,0,0,0}
  },
  // S
  {
    {0,0,0,0},
    {0,1,1,0},
    {1,1,0,0},
    {0,0,0,0}
  },
  // T
  {
    {0,0,0,0},
    {0,1,0,0},
    {1,1,1,0},
    {0,0,0,0}
  },
  // Z
  {
    {0,0,0,0},
    {1,1,0,0},
    {0,1,1,0},
    {0,0,0,0}
  }
};

// Tetromino colors (GRB)
const uint32_t tetrominoColors[7] = {
  strip.Color(0,255,255), // I - cyan
  strip.Color(0,0,255),   // J - blue
  strip.Color(255,165,0), // L - orange
  strip.Color(255,255,0), // O - yellow
  strip.Color(0,255,0),   // S - green
  strip.Color(128,0,128), // T - purple
  strip.Color(255,0,0)    // Z - red
};

// Current piece state
int currentTetromino, rotation, posX, posY;
uint8_t currentPiece[4][4]; // Store current piece with rotation applied
bool gameOver = false;
unsigned long lastDrop = 0;
const unsigned long dropInterval = 600; // ms

// Map (x, y) to LED index for serpentine wiring
int xyToIndex(int x, int y) {
  if (y % 2 == 0) {
    return y * MATRIX_WIDTH + x;
  } else {
    return y * MATRIX_WIDTH + (MATRIX_WIDTH - 1 - x);
  }
}

void setup() {
  Serial.begin(115200);
  delay(100);
  Serial.println("\n\nStarting Tetris...");
  
  // WiFiManager initialization
  wifiManager.autoConnect("TetrisClock");
  
  Serial.println("WiFi connected!");
  IPAddress ip = WiFi.localIP();
  Serial.print("Local IP address: ");
  Serial.println(ip);
  
  strip.begin();
  strip.show();
  server.on("/", handleRoot);
  server.on("/restart", handleRestart);
  server.begin();
  spawnTetromino();
  drawBoard();  // Draw the initial piece before game loop starts
  // Start WebSocket server for low-latency controls and score updates
  webSocket.begin();
  webSocket.onEvent(webSocketEvent);
}

// Send current score to all connected WebSocket clients
void sendScoreToClients() {
  String msg = "score:" + String(score);
  webSocket.broadcastTXT(msg);
}

// Spawn a new tetromino at the top
void spawnTetromino() {
  currentTetromino = random(0, 7);
  rotation = 0;
  posX = 3; // Centered
  posY = -2;  // Spawn one line above visible area
  // Copy initial tetromino to current piece
  for (int i = 0; i < 4; i++) {
    for (int j = 0; j < 4; j++) {
      currentPiece[i][j] = tetrominos[currentTetromino][i][j];
    }
  }
  lastDrop = millis();  // Reset timer so piece has time to display before first drop
}

// Check collision for current piece at (x, y) with rotation
bool checkCollision(int x, int y, int rot) {
  for (int i = 0; i < 4; i++) {
    for (int j = 0; j < 4; j++) {
      if (currentPiece[i][j]) {
        int nx = x + j;
        int ny = y + i;
        // Only check collisions with boundaries and board for visible area
        if (nx < 0 || nx >= MATRIX_WIDTH) return true;
        if (ny >= MATRIX_HEIGHT) return true;  // Piece hit bottom
        if (ny >= 0 && board[ny][nx]) return true;  // Only check board collision if visible
      }
    }
  }
  return false;
}

// Place current piece on the board
void placeTetromino() {
  for (int i = 0; i < 4; i++) {
    for (int j = 0; j < 4; j++) {
      if (currentPiece[i][j]) {
        int nx = posX + j;
        int ny = posY + i;
        if (nx >= 0 && nx < MATRIX_WIDTH && ny >= 0 && ny < MATRIX_HEIGHT) {
          board[ny][nx] = currentTetromino + 1;
        }
      }
    }
  }
}

// Clear full lines and animate
void clearLines() {
  for (int y = 0; y < MATRIX_HEIGHT; y++) {
    bool full = true;
    for (int x = 0; x < MATRIX_WIDTH; x++) {
      if (!board[y][x]) {
        full = false;
        break;
      }
    }
    if (full) {
      // Animate line
      for (int t = 0; t < 3; t++) {
        for (int x = 0; x < MATRIX_WIDTH; x++) {
          strip.setPixelColor(xyToIndex(x, y), strip.Color(255,255,255));
        }
        strip.show();
        delay(80);
        for (int x = 0; x < MATRIX_WIDTH; x++) {
          strip.setPixelColor(xyToIndex(x, y), 0);
        }
        strip.show();
        delay(80);
      }
      // Remove line and shift down
      for (int yy = y; yy > 0; yy--) {
        for (int x = 0; x < MATRIX_WIDTH; x++) {
          board[yy][x] = board[yy-1][x];
        }
      }
      for (int x = 0; x < MATRIX_WIDTH; x++) board[0][x] = 0;
      score += 10;
      sendScoreToClients();
    }
  }
}

// Draw the board and current piece
void drawBoard() {
  strip.clear();
  // Draw placed blocks
  for (int y = 0; y < MATRIX_HEIGHT; y++) {
    for (int x = 0; x < MATRIX_WIDTH; x++) {
      if (board[y][x]) {
        strip.setPixelColor(xyToIndex(x, y), tetrominoColors[board[y][x]-1]);
      }
    }
  }
  // Draw current piece
  for (int i = 0; i < 4; i++) {
    for (int j = 0; j < 4; j++) {
      if (currentPiece[i][j]) {
        int nx = posX + j;
        int ny = posY + i;
        if (nx >= 0 && nx < MATRIX_WIDTH && ny >= 0 && ny < MATRIX_HEIGHT) {
          strip.setPixelColor(xyToIndex(nx, ny), tetrominoColors[currentTetromino]);
        }
      }
    }
  }
  strip.show();
}

// Rotate tetromino (clockwise)
void rotateTetromino() {
  uint8_t rotated[4][4];
  for (int i = 0; i < 4; i++) {
    for (int j = 0; j < 4; j++) {
      rotated[j][3-i] = currentPiece[i][j];
    }
  }
  // Check collision for rotated piece
  for (int i = 0; i < 4; i++) {
    for (int j = 0; j < 4; j++) {
      if (rotated[i][j]) {
        int nx = posX + j;
        int ny = posY + i;
        if (nx < 0 || nx >= MATRIX_WIDTH || ny >= MATRIX_HEIGHT || (ny >= 0 && board[ny][nx])) {
          return; // Collision, do not rotate
        }
      }
    }
  }
  // Apply rotation
  for (int i = 0; i < 4; i++) {
    for (int j = 0; j < 4; j++) {
      currentPiece[i][j] = rotated[i][j];
    }
  }
  drawBoard();
}
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

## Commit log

2024-01-17 Initial release
    [Berndeutsch_121.dxf, ClockFace_11x11_Berndeutsch.ods]
2024-01-21 bugfix: toggle-buttons ios
2024-03-20 tsüritüütsch
    [Zuerideutsch_121.dxf]
2024-03-21 custom clockfaces generated
    [Berndeutsch_121.dxf, Zuerideutsch_121.dxf]
2024-03-26 updated minute-ticks
    [Berndeutsch_121.dxf, Zuerideutsch_121.dxf]
2024-03-26 updated eufi
    [Berndeutsch_121.dxf, Zuerideutsch_121.dxf]
2024-03-26 its the final clockface
    [Berndeutsch_121.dxf, Zuerideutsch_121.dxf]
2024-04-05 new clock-face; power-button initial
2024-04-06 power-button backend
2024-04-07 power button added search word clock removed
2024-04-18 loop through local ip
    [Snake_Array.xlsx]
2024-04-19 user-manual and full-screen-svg 25x25/50x50 added
    [Snake_Array.xlsx]
2024-05-20 mdns-server added
    [Berndeutsch_121_25x25_Laser.dxf, Berndeutsch_121_50x50_Laser.dxf, Zuerideutsch_121_25x25_Laser.dxf]
2024-06-11 3D-Grid 25x25 added
    [tinker.obj]
2024-06-28 3d-Models added
    [WordClock 25x25 slim.stl, WordClock_25x25.stl, WordClock_50x50_A.stl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]
2024-08-07 clockfaces added
    [Berndeutsch_121.dxf, Berndeutsch_121_25x25_Laser.dxf, Berndeutsch_121_50x50_Laser.dxf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]
2024-09-16 Bugfix: mastermind when power off
2024-09-17 Feature: Ghosthour initial release
    [Snake_Array.xlsx]
2024-09-24 wordguessr: second step
    [Snake_Array.xlsx]
2024-10-05 new words in excel
    [Snake_Array.xlsx]
2024-10-05 bugfix too many words
    [Snake_Array.xlsx]
2024-10-13 wordguessr: words stored in progmem
    [Snake_Array.xlsx]
2025-03-16 minify web app on arduino
2025-03-18 bugfix: power on/off delayed in app, reset snake score for 2nd game
2025-12-01 Bugfix: sächSIbni ClassList
    [Snake_Array.xlsx]
2025-12-15 serial.prints removed
2026-01-16 led test moved to branch
2026-01-26 bugfix no effects when power off
2026-02-14 Stencil-Clockface updated
    [Berndeutsch_121_50x50_Stencil.dxf]
2026-02-14 Closed open Path in Stencil-Clockface
    [Berndeutsch_121_50x50_Stencil.dxf]
2026-02-22 use touch sensor on D5 to toggle power
2026-03-11 LED-Plate for Lasercutter
2026-03-13 LED-Plate for Creality Falcon A1 fixed
2026-04-23 Cleanup Files
    [ClockFace_11x11_Berndeutsch.ods, Snake_Array.xlsx, USB-Cable Mount.stl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]
2026-05-07 LED-Platte 9x9 added
2026-05-10 LED-Plate for 9x9
2026-05-10 9x9 Grid optimized
    [WordClock_9x9.stl]
2026-05-12 adapted for esp32
2026-05-21 hybrid solution for esp32/esp8266
2026-05-21 speed of snake game controlled with millis
2026-05-21 Snake speed in millis fixed
2026-05-21 Touch-Sensor mit Feature-Switch eingebaut
2026-05-21 effects-animations after power or effect change
2026-05-24 effectChange fixed, esp32 final release
2026-07-16 X und L2 hinzugefügt
2026-07-16 Select & Start-Button hinzugefügt
2026-09-01 buttons logged with nimBLEDevice working
2026-09-01 all buttons logged with nimBLEDevice
2026-09-02 Compile-Instructions for huge app added
    [partitions.csv]
2026-09-04 serial.print entfernt, gitignore ergänzt
2026-09-10 show controller pairing state on wifi-led
2026-09-22 repo cleanup
    [partitions.csv]
2026-09-28 help-buttons for games

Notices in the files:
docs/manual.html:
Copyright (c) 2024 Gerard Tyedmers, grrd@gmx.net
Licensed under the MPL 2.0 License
